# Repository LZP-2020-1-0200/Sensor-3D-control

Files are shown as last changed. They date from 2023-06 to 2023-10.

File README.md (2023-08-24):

# Sensor-3D-control
Programmambe sensor stage

## SCPI reference

### `*IDN?`

Prints identificator.

### `*RST`

Resets the state without restarting the entire module.

### `motor?`

prints all motor coordinates

Format: `<x> <y> <z>`

### `motor [X|Y|Z] `_`val`_

Sets the target coordinate to all motors or one motor specifically to _`val`_ switches state to 'targeting'

### `motor:lock?`

Prints out all motor lock states.

Format: `<1|0> <1|0> <1|0>`

Only prints `0` if that motor is completely unlocked, otherwise `1`

### `motor:lock [X|Y|Z] <ON|OFF>`

Locks/unlocks one or all motors.

Overrides any previous action that motors were doing. Both `ON` and `OFF` will stop the stepper(s) in their tracks

### `motor:state?`

Prints out the state of all motors.

Format: `<X.state> <Y.state> <Z.state>`

|State number|State name| Description |
|--|--|--|
|0|Disabled|The stepper is disabled (all magnets are off).|
|1|Idle|The stepper isn't moving, however some of the magnets are enabled and lock it in place.|
|2|Homing| The stepper is attempting to locate the start switch to reset it's internal coordinate system. Coordinate system resets only after the homing sequence is complete.|
|3|Targeting| The stepper is performing the targeting sequence.|

### `motor:state:default?`

Prints out the default state of all motors.

Format: `<default_state>`

States similar to `motor:state?` but prints out the default state instead of the current state.
State can be only 0 (Disabled) or 1 (Idle)

### `motor:state:default <0|1>`

Sets the default state of all motors.

State can be only 0 (Disabled) or 1 (Idle)

### `motor:end:<X|Y|Z>?`

prints out end switch status for specified axis.

Format: `<start> <end>`

`1` - switch triggered
`0` - switch not triggered

### `home`

Sets mode to 'homing' for all motors.

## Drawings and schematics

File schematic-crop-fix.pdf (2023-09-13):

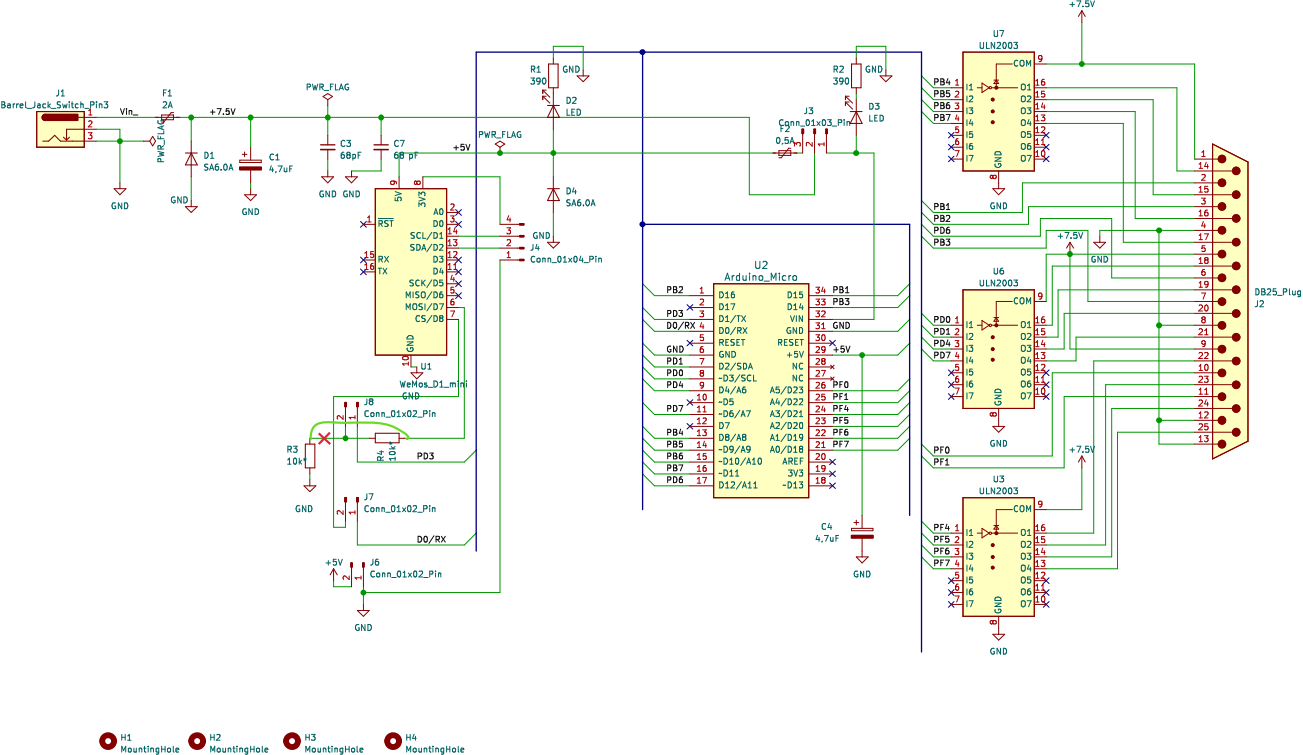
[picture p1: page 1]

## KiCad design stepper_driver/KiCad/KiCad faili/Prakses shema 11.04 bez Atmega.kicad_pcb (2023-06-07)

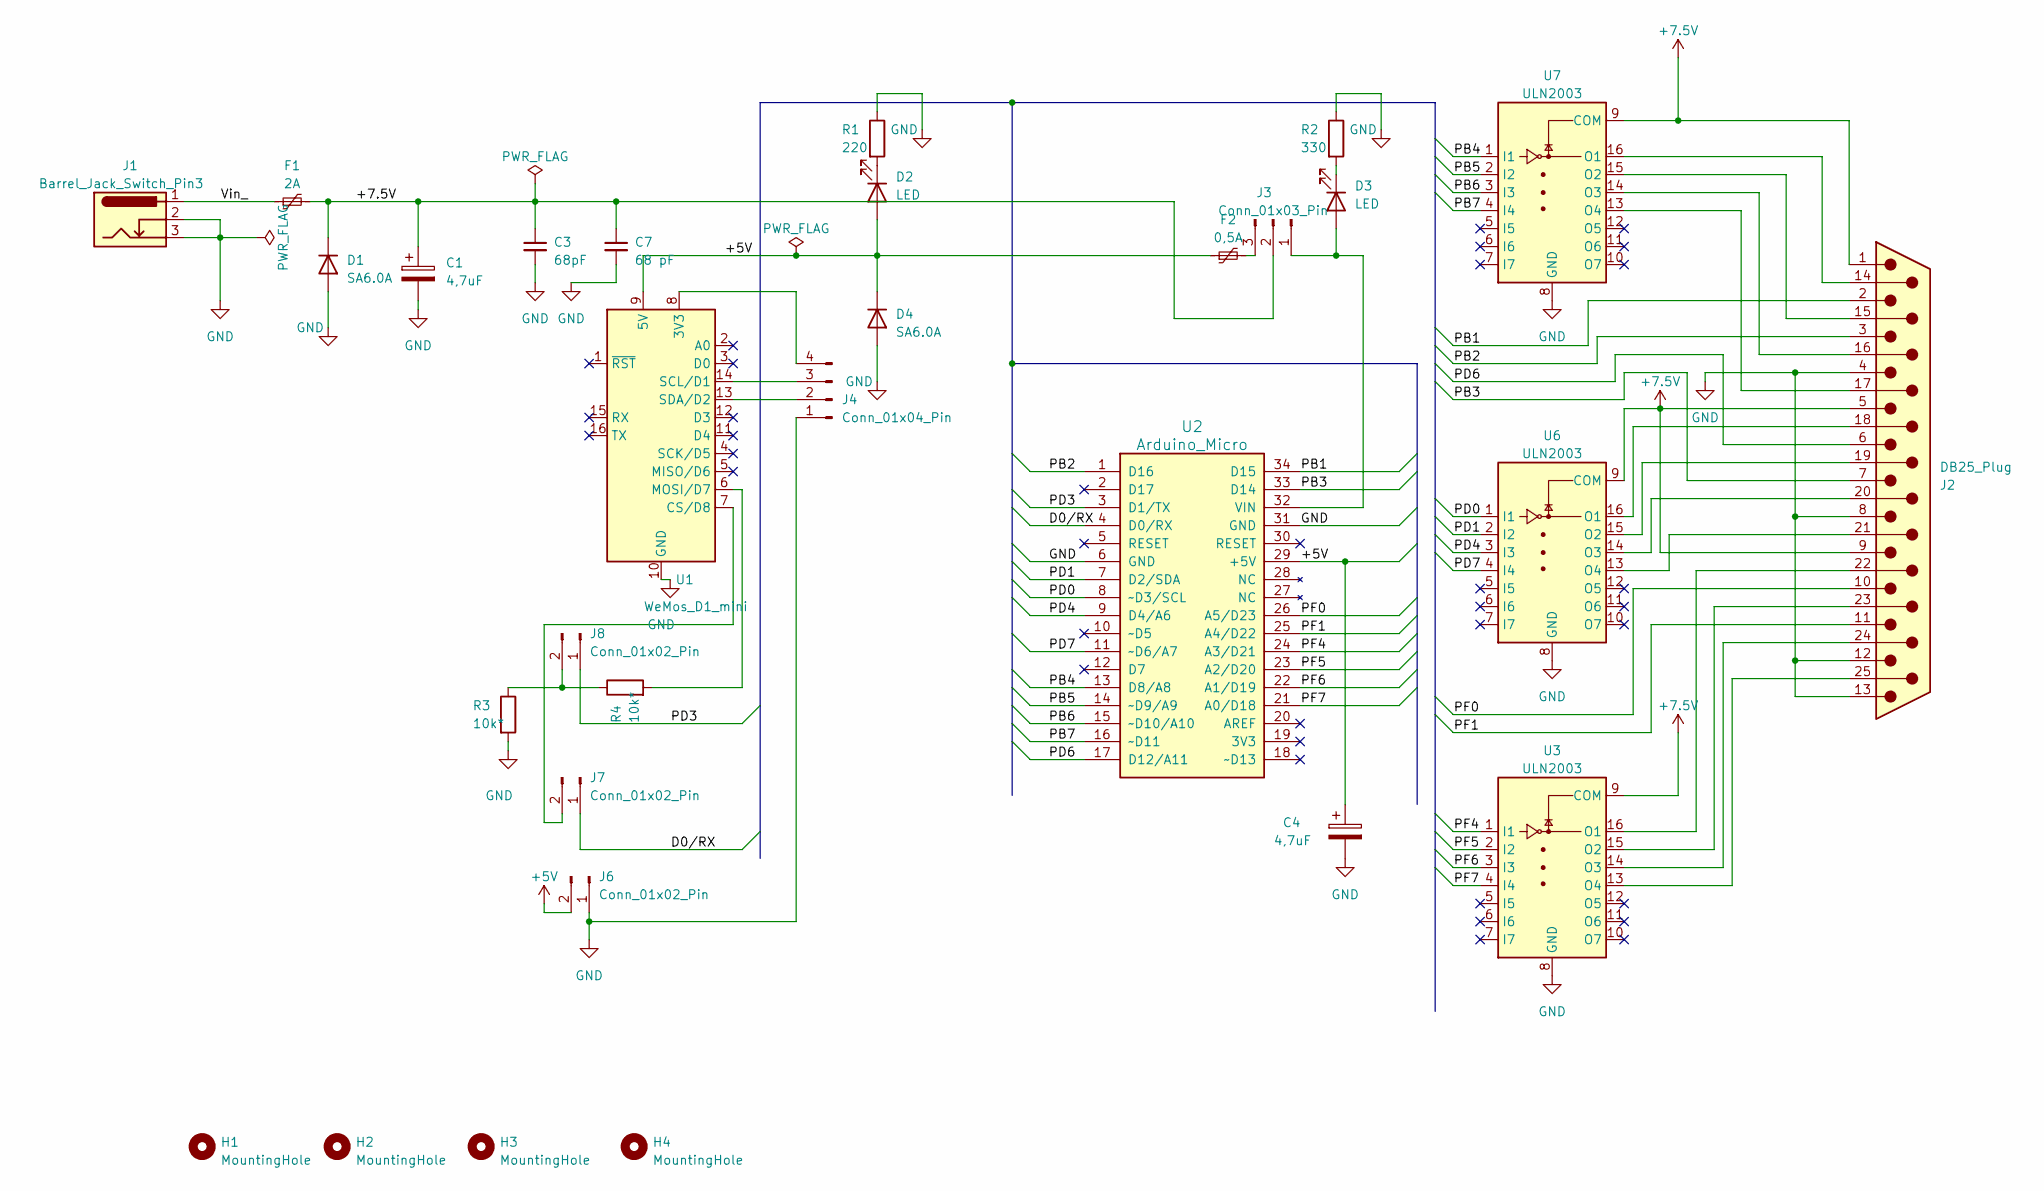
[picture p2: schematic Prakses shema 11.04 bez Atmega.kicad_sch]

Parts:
C1, C4: 4,7uF; CP_Radial_D10.0mm_P3.80mm
C3: 68pF; C_Disc_D5.0mm_W2.5mm_P5.00mm
C7: 68 pF; C_Disc_D5.0mm_W2.5mm_P5.00mm
D1, D4: SA6.0A; D_DO-15_P12.70mm_Horizontal
D2, D3: LED; LED_D3.0mm
F1: 2A; Fuseholder_Cylinder-5x20mm_Stelvio-Kontek_PTF78_Horizontal_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
F2: 0,5A; Fuseholder_Cylinder-5x20mm_Stelvio-Kontek_PTF78_Horizontal_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
H1, H2, H3, H4: MountingHole; MountingHole_3.2mm_M3
J1: Barrel_Jack_Switch_Pin3; BarrelJack_GCT_DCJ200-10-A_Horizontal
J2: DB25_Plug; DSUB-25_Male_Horizontal_P2.77x2.84mm_EdgePinOffset9.90mm_Ho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
J3: Conn_01x03_Pin; PinSocket_1x03_P2.54mm_Vertical
J4: Conn_01x04_Pin; PinHeader_1x04_P2.54mm_Vertical
J6, J7, J8: Conn_01x02_Pin; PinHeader_1x02_P2.54mm_Vertical
R1: 220; R_Axial_DIN0207_L6.3mm_D2.5mm_P10.16mm_Horizontal
R2: 330; R_Axial_DIN0207_L6.3mm_D2.5mm_P10.16mm_Horizontal
R3, R4: 10k*; R_Axial_DIN0207_L6.3mm_D2.5mm_P10.16mm_Horizontal
U1: WeMos_D1_mini; WEMOS_D1_mini_light
U2: Arduino_Micro
U3, U6, U7: ULN2003; DIP-16_W7.62mm_LongPads

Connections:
+5V: C4.1, D2.2 (A), D4.1 (K), F2.1, J6.2, U1.9 (5V), U2.29 (+5V)
+7.5V: C1.1, C3.1, C7.1, D1.1 (K), F1.2, J2.1, J2.5, J2.9, J3.2, U3.9 (COM), U6.9 (COM), U7.9 (COM)
/D0/RX: J7.1, U2.4 (D0/RX)
/PB1: J2.2, U2.34 (D15)
/PB2: J2.3, U2.1 (D16)
/PB3: J2.7, U2.33 (D14)
/PB4: U2.13 (D8/A8), U7.1 (I1)
/PB5: U2.14 (~D9/A9), U7.2 (I2)
/PB6: U2.15 (~D10/A10), U7.3 (I3)
/PB7: U2.16 (~D11), U7.4 (I4)
/PD0: U2.8 (~D3/SCL), U6.1 (I1)
/PD1: U2.7 (D2/SDA), U6.2 (I2)
/PD3: J8.1, U2.3 (D1/TX)
/PD4: U2.9 (D4/A6), U6.3 (I3)
/PD6: J2.6, U2.17 (D12/A11)
/PD7: U2.11 (~D6/A7), U6.4 (I4)
/PF0: J2.10, U2.26 (A5/D23)
/PF1: J2.11, U2.25 (A4/D22)
/PF4: U2.24 (A3/D21), U3.1 (I1)
/PF5: U2.23 (A2/D20), U3.2 (I2)
/PF6: U2.22 (A1/D19), U3.3 (I3)
/PF7: U2.21 (A0/D18), U3.4 (I4)
/Vin_: F1.1, J1.1
GND: C1.2, C3.2, C4.2, C7.2, D1.2 (A), D4.2 (A), J1.2, J1.3, J2.4, J2.8, J2.12, J2.13, J4.1, J6.1, R1.1, R2.1, R3.2, U1.10 (GND), U2.6 (GND), U2.31 (GND), U3.8 (GND), U6.8 (GND), U7.8 (GND)
unnamed: D2.1 (K), R1.2
unnamed: D3.2 (A), J3.1, U2.32 (VIN)
unnamed: D3.1 (K), R2.2
unnamed: J2.14, U7.16 (O1)
unnamed: J2.15, U7.15 (O2)
unnamed: J2.16, U7.14 (O3)
unnamed: J2.17, U7.13 (O4)
unnamed: J2.18, U6.16 (O1)
unnamed: J2.19, U6.15 (O2)
unnamed: J2.20, U6.14 (O3)
unnamed: J2.21, U6.13 (O4)
unnamed: J2.22, U3.16 (O1)
unnamed: J2.23, U3.15 (O2)
unnamed: J2.24, U3.14 (O3)
unnamed: J2.25, U3.13 (O4)
unnamed: F2.2, J3.3
unnamed: J4.2, U1.13 (SDA/D2)
unnamed: J4.3, U1.14 (SCL/D1)
unnamed: J4.4, U1.8 (3V3)
unnamed: J7.2, U1.7 (CS/D8)
unnamed: J8.2, R3.1, R4.1
unnamed: R4.2, U1.6 (MOSI/D7)

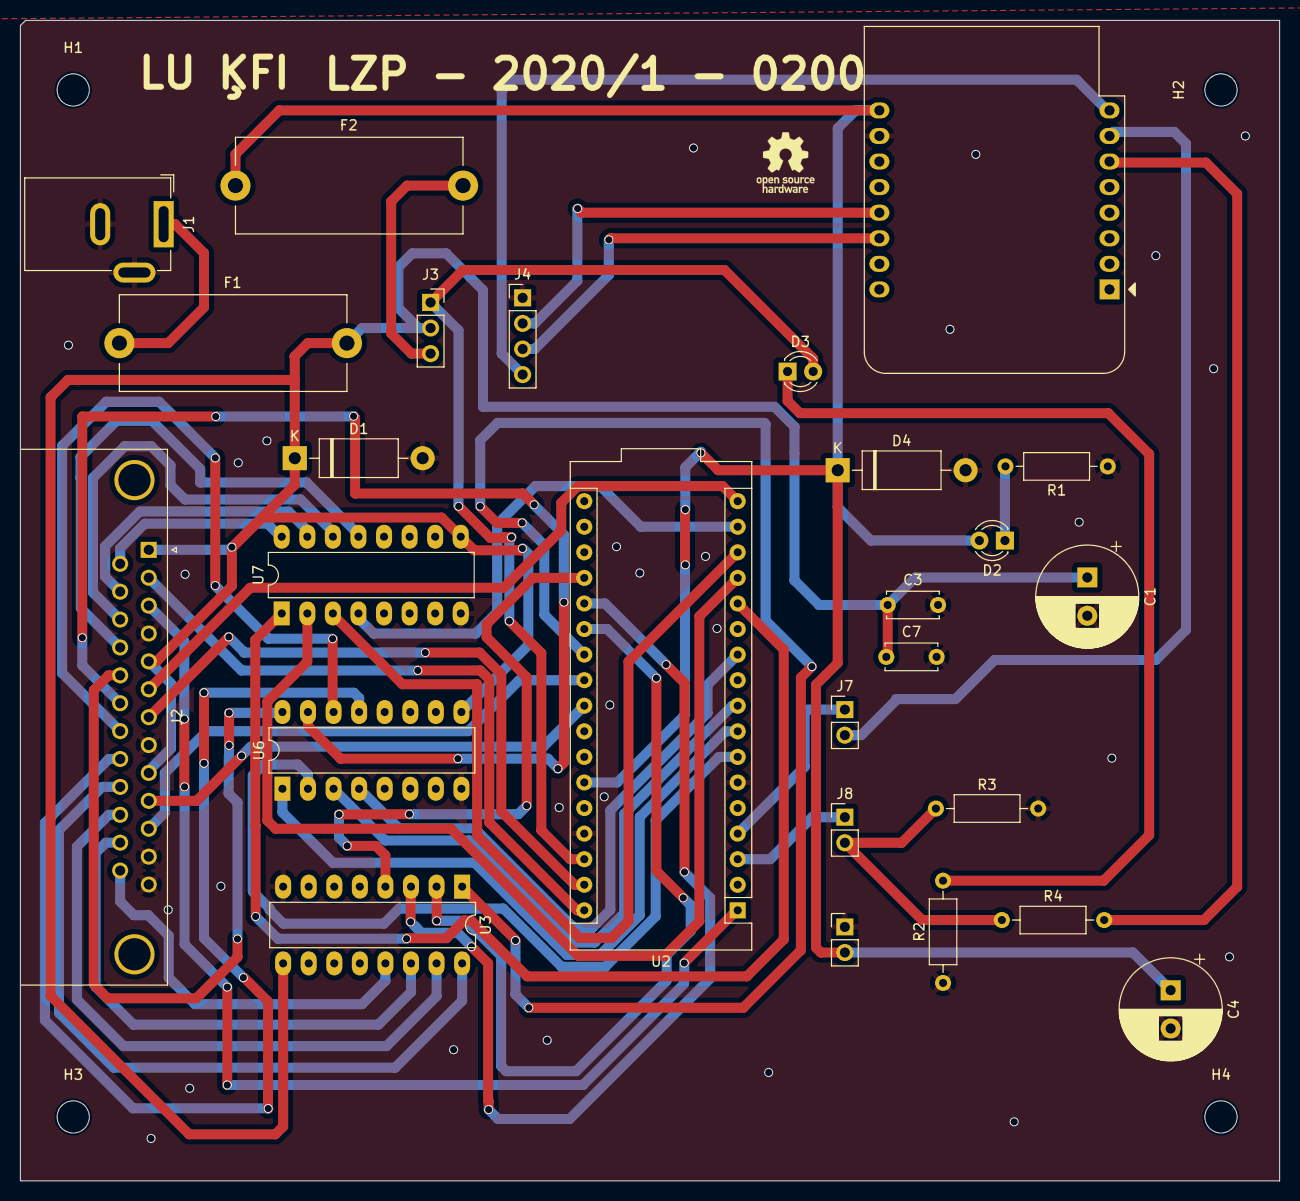
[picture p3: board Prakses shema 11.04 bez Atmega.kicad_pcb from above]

Board: 2 copper layers, 125.1 x 115.3 mm, 30 parts (0 on the bottom side), 46 nets.

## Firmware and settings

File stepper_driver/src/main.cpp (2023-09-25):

#include <Arduino.h>
#include "scpi2.h"
#include "stepper.h"
#include "endSwitch.h"
#include "stepperController.h"
#define DEFAULT_BAUD 9600



StepperController& xMotor = StepperController::xMotor;
StepperController& yMotor = StepperController::yMotor;
StepperController& zMotor = StepperController::zMotor;

extern scpi::Command baseCMD;

scpi::scpi2 inputHandler = scpi::scpi2(Serial1, baseCMD);

#ifndef PIO_UNIT_TESTING
void setup()
{
    Serial.begin(DEFAULT_BAUD);
    Serial.setTimeout(100);
    Serial1.begin(DEFAULT_BAUD);
    Serial1.setTimeout(100);
    StepperController::motors[0]=&xMotor;
    StepperController::motors[1]=&yMotor;
    StepperController::motors[2]=&zMotor;
    //s.set_direction(STEPPER_UP);
    xMotor.setDelay("100");
    yMotor.setDelay("100");
    zMotor.setDelay("200");
    //zMotor.setTarget(30000);
    delay(3000);
    Serial.print("Initialized\r\n");
    baseCMD.dump();
    pinMode(LED_BUILTIN, OUTPUT);
    pinMode(LED_BUILTIN_RX, OUTPUT);
    pinMode(LED_BUILTIN_TX, OUTPUT);
    digitalWrite(LED_BUILTIN_RX, HIGH);
    digitalWrite(LED_BUILTIN_TX, HIGH);
    digitalWrite(LED_BUILTIN, HIGH);
    delay(1000);
    digitalWrite(LED_BUILTIN_RX, LOW);
    digitalWrite(LED_BUILTIN_TX, LOW);
    digitalWrite(LED_BUILTIN, LOW);
    delay(1000);
    //zMotor.setMode(StepperController::mode::homing);
}

void loop()
{
    inputHandler.update();
    endSwitch::Xlow.printEdge();
    endSwitch::Xhigh.printEdge();
    endSwitch::Ylow.printEdge();
    endSwitch::Yhigh.printEdge();
    endSwitch::Zlow.printEdge();
    endSwitch::Zhigh.printEdge();
    bool xActive = !(
        xMotor.getMode()==StepperController::mode::disabled ||
        xMotor.getMode()==StepperController::mode::idle
        );
    bool yActive = !(
        yMotor.getMode()==StepperController::mode::disabled ||
        yMotor.getMode()==StepperController::mode::idle
        );
    bool zActive = !(
        zMotor.getMode()==StepperController::mode::disabled ||
        zMotor.getMode()==StepperController::mode::idle
        );
        
    pinMode(LED_BUILTIN, OUTPUT);
    pinMode(LED_BUILTIN_RX, OUTPUT);
    pinMode(LED_BUILTIN_TX, OUTPUT);
    if(xActive) digitalWrite(LED_BUILTIN_RX, millis()%250<125);
    else digitalWrite(LED_BUILTIN_RX, LOW);
    if(yActive) digitalWrite(LED_BUILTIN_TX, millis()%250<125);
    else digitalWrite(LED_BUILTIN_TX, LOW);
    if(zActive) digitalWrite(LED_BUILTIN, millis()%250<125);
    else digitalWrite(LED_BUILTIN, LOW);
}

#endif

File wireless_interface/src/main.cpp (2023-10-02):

#include <Arduino.h>
#include <ESP8266WiFi.h>
#include <httpToSerial.h>
#include "secrets.h"
#include <LittleFS.h>

// small helper function to get the size of an array at compile time
// without this, we would have to pass the size of the routes array manually
// to the HttpToSerial constructor
template <size_t N>
static constexpr size_t arrSize(PassthroughRoute (&)[N]) {
    return N;
}

const char* motorParameters[] = {"motor", "coord"};
PassthroughRoute routes[] = {
    PassthroughRoute("/motorq", "motor?"),
    std::move(*PassthroughRoute::makeRoute("/motor", "motor", motorParameters))
};


HttpToSerial httpToSerial(
    Serial, 9600, 80,
    "esp8266",
    ACCESS_USERNAME, ACCESS_PASSWORD,
    routes,
    arrSize(routes)
);

void setup() {
    Serial.begin(9600);
    if(!LittleFS.begin()){
        Serial.println("An Error has occurred while mounting SPIFFS");
        return;
    }
    // clear console
    //Serial.println("\x1b[1;1H\x1b[3J\x1b[1J\x1b[1;1H");
    File file = LittleFS.open("splash.txt", "r");
    if(!file){
        Serial.println("Failed to open file for reading");
        return;
    }
    while(file.available()){
        Serial.write(file.read());
    }
    file.close();

    Serial.println(F("Setup started"));
    WiFi.begin(WIFI_SSID, WIFI_PASSWORD);
    int retries = 0;
    const int maxRetries = 30;
    while ((WiFi.status() != WL_CONNECTED) && (retries < maxRetries)) {
        retries++;
        delay(500);
        Serial.print(".");
        wl_status_t status = WiFi.status();
        if(status == WL_CONNECT_FAILED) {
            Serial.println(F("Connection failed!"));
        } else if (status == WL_NO_SSID_AVAIL) {
            Serial.println(F("SSID not available!"));
        }
    }
    Serial.println();
    if (retries > maxRetries-1) {
        Serial.println(F("WiFi connection FAILED"));
    }
    if (WiFi.status() == WL_CONNECTED) {
        Serial.println(F("WiFi connected!"));
        Serial.println("IP address: ");
        Serial.println(WiFi.localIP());
    }
    Serial.println(F("Setup ready"));
    Serial.flush();
    Serial.end();
    Serial.setTimeout(3000);
    httpToSerial.start();
    Serial.swap();
}

void loop() {
    httpToSerial.loop();
}

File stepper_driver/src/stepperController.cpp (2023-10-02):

#include "stepperController.h"
#include "stepper.h"
#include "endSwitch.h"
#include "reporter.h"

StepperController* StepperController::motors[STEPPER_COUNT];

StepperController::StepperController(Stepper& motor, endSwitch& startSwitch, endSwitch& endSwitch)
    : motor(motor), start(startSwitch), end(endSwitch) { };

StepperController::~StepperController(){

}

int StepperController::get_position(void) const {
    return motor.getPosition();
}

void StepperController::updateTimers(){
    if(direction_change_timer > 0) direction_change_timer--;
    if(millisecond_counter>step_delay_milliseconds){
        millisecond_counter = 0;
        updateStepper();
    }
    millisecond_counter++;
}

StepperController::direction_t StepperController::deltaToDirection(int delta){
    if (delta == 0) return StepperController::direction_t::STEPPER_PAUSE;
    if (delta > 0) return StepperController::direction_t::STEPPER_UP;
    return StepperController::direction_t::STEPPER_DOWN;
}



void StepperController::setHome(void) {
    homeModeData.homingState = 0;
    homeModeData.homingOvershootCounter = 0;
    homeModeData.fWiggle = 0;
    homeModeData.bWiggle = 0;
    homeModeData.wiggle = 0;
    currentMode = mode::homing;
}

void StepperController::setTarget (int x) {
    targetModeData.targetPos = x;
    targetModeData.targetState = T_START;
    currentMode = mode::target;
}

void StepperController::setTargetRaw(int target) {
    rawModeData.targetPos = target;
    currentMode = mode::raw;
}

void StepperController::tick(){
    start.update();
    end.update();
    updateTimers();
    //updateStepper();
    if(currentMode == mode::target) {
        if(targetedMove()){
            currentMode = defaultMode;
            Serial.print("reached.\r\n");
        }
    } else if(currentMode == mode::homing) {
        if(homingMove()) {
            currentMode = defaultMode;
            Serial.print("homed.\r\n");
        }
    } else if(currentMode == mode::idle) {
        direction = direction_t::STEPPER_PAUSE;
    } else if(currentMode == mode::disabled) {
        direction = direction_t::STEPPER_DISABLED;
    } else if (currentMode == mode::raw) {
        if(rawMove()) {
            currentMode = defaultMode;
            Serial.print("reached.\r\n");
        }
    }
}

bool StepperController::rawMove() {
    if (motor.getPosition() < rawModeData.targetPos) {
        if(end.getState()) {
            direction = direction_t::STEPPER_DISABLED;
            return true;
        }
        direction = direction_t::STEPPER_UP;
        return false;
    } else if (motor.getPosition() > rawModeData.targetPos) {
        if(start.getState()) {
            direction = direction_t::STEPPER_DISABLED;
            return true;
        }
        direction = direction_t::STEPPER_DOWN;
        return false;
    }
    direction = direction_t::STEPPER_DISABLED;
    return true;
}

// this is essentially a state machine with the advantage
// of transitions happening on the same iteration
bool StepperController::homingMove(){
    //Serial.print(homeModeData.homingState, DEC);
    //Serial.print("\n");
    switch (homeModeData.homingState)
    {
        // move off of limit switch
        case 0:
        if (start.getState()) {
            direction = direction_t::STEPPER_UP;
            return false;
        }
        homeModeData.homingOvershootCounter = 0;
        homeModeData.homingState++;

        // overshoot
        case 1:
        if(homeModeData.homingOvershootCounter<1000*step_delay_milliseconds){
            homeModeData.homingOvershootCounter++;
            direction = direction_t::STEPPER_UP;
            return false;
        }
        homeModeData.homingState++;

        // approach switch
        case 2:
        if (!start.getState()) {
            direction = direction_t::STEPPER_DOWN;
            return false;
        }
        homeModeData.homingOvershootCounter = 0;
        homeModeData.homingState++;

        //small overshoot
        case 3:
        if(homeModeData.homingOvershootCounter<50*step_delay_milliseconds){
            homeModeData.homingOvershootCounter++;
            direction = direction_t::STEPPER_DOWN;
            return false;
        }
        homeModeData.homingState++;

        // overshoot a bit because the switch may release because
        // of the screw releasing pressure on the switch

        // count up wiggle steps
        case 4:
        if (start.getState()) {
            direction = direction_t::STEPPER_UP;
            homeModeData.fWiggle++;
            return false;
        }
        homeModeData.homingOvershootCounter = 0;
        homeModeData.homingState++;

        // overshoot
        case 5:
        if(homeModeData.homingOvershootCounter<50*step_delay_milliseconds){
            homeModeData.homingOvershootCounter++;
            direction = direction_t::STEPPER_UP;
            return false;
        }
        homeModeData.homingState++;


        // return to switch to set (0,0) and count down wiggle steps
        case 6:
        if (!start.getState()) {
            direction = direction_t::STEPPER_DOWN;
            homeModeData.bWiggle++;
            return false;
        }
        homeModeData.wiggle = (homeModeData.bWiggle>homeModeData.fWiggle) ? homeModeData.bWiggle : homeModeData.fWiggle;
        homeModeData.wiggle = homeModeData.wiggle/step_delay_milliseconds;
        motor.resetPosition();
        direction = direction_t::STEPPER_PAUSE;
        homeModeData.homingState++;
        Serial.print("bWiggle: ");
        Serial.print(homeModeData.bWiggle/step_delay_milliseconds, DEC);
        Serial.print("\r\n");
        Serial.print("fWiggle: ");
        Serial.print(homeModeData.fWiggle/step_delay_milliseconds, DEC);
        
    }
    return true;
}
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

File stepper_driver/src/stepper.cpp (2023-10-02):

#include "stepper.h"

// constrain to this file
static const uint8_t sequence[] = //{(1 << DDB4), (1 << DDB5), (1 << DDB6), (1 << DDB7)};
{
    0b1100,
    0b0100,
    0b0110,
    0b0010,
    0b0011,
    0b0001,
    0b1001
};

Stepper::motorData::motorData(
    volatile uint8_t* port,
    volatile uint8_t* dataDirRegister,
    int pin1, int pin2, int pin3, int pin4)
    : port(port),
      dataDirRegister(dataDirRegister),
      pins{pin1, pin2, pin3, pin4} {
    
};

Stepper::Stepper(motorData motor)
    : motor(motor),
      motor_pins(
        (1<<motor.pins[0]) |
        (1<<motor.pins[1]) |
        (1<<motor.pins[2]) |
        (1<<motor.pins[3])
        ), motor_mask(~motor_pins) {
    cli();
    //set motor pins as outputs
    *(motor.dataDirRegister) |= motor_pins;
    sei();
};

void Stepper::unlock(void){
    *(motor.port) &= motor_mask;
}

void Stepper::lock(void){
    volatile uint8_t stepper_bits = *(motor.port) & motor_mask;// clear all motor bits
    uint8_t seqN = (position + offset) & 7;
    for(int i=0;i<4;i++){
        stepper_bits|= (0b1&(sequence[seqN]>>i))<<motor.pins[i];
    }
    *(motor.port) = stepper_bits;
}

void Stepper::forward(void) {
    position++;
    lock();
}

void Stepper::backward(void){
    position--;
    lock();
}

int Stepper::getPosition(void) const {
    return position;
}

void Stepper::resetPosition(void){
    offset = (position + offset) & 7;
    position = 0;
}

void Stepper::reset(void){
    resetPosition();
    unlock();
    offset = 0;
    position = 0;
}


#define STEPPER_SETUP(port, pin1, pin2, pin3, pin4) \
    &PORT ## port,\
    &DDR ## port,\
    DD ## port ## pin1,\
    DD ## port ## pin2,\
    DD ## port ## pin3,\
    DD ## port ## pin4

#define STEPPER_SETUP_R(port, pin1, pin2, pin3, pin4) STEPPER_SETUP(port, pin4, pin3, pin2, pin1)

Stepper Stepper::yStepper{motorData{STEPPER_SETUP_R(D,0,4,1,7)}};

Stepper Stepper::xStepper{motorData{STEPPER_SETUP(B,4,6,5,7)}};

Stepper Stepper::zStepper{motorData{STEPPER_SETUP(F,4,6,5,7)}};

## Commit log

2023-03-07 led active low
2023-03-07 timer3 strādā
2023-03-08 motors griežas
2023-03-14 Stepper class changes with command support
2023-03-14 Konektora apraksts
    [Pinu sadalījuma tabula.csv]
2023-06-07 Add files via upload
    Man šķiet, ka šis ir īstais
    [Prakses shema 11.04 bez Atmega.kicad_pcb, Prakses shema 11.04 bez Atmega.kicad_sch]
2023-06-26 stepper class setup
2023-06-26 end switch class
2023-06-26 event clock class with 1ms timer set up
2023-06-26 stepper controller class added It manages multilayered state machines that influence a stepper and 2 end switches
2023-08-22 carriage returns
2023-08-22 stepper controller refactor
2023-08-24 end switch reset
2023-08-24 stepper reset
2023-08-24 Stepper controller update
2023-08-24 copy constructor deletion and serial print
2023-08-24 motor state default get set
2023-08-28 moved files downwards
    [Pinu sadalījuma tabula.csv, Prakses shema 11.04 bez Atmega.kicad_pcb, Prakses shema 11.04 bez Atmega.kicad_sch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]
2023-09-05 wireless interface first commit
2023-09-08 fixed messages to respond passthrough routes take up less memory
    [main.cpp, motor.cpp, motorEnds.cpp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]
2023-10-02 flipped y axis
2023-10-02 extra motor command option
